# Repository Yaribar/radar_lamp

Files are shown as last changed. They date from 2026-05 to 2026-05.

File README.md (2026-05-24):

# Radar Lamp

ESP32-C3 Super Mini project that dims a lamp based on distance measured by an Acconeer XE121 radar sensor (A121 chip).

## Hardware

- **MCU**: ESP32-C3 Super Mini
- **Sensor**: Acconeer XE121 (A121 radar)

## Wiring

| Signal | ESP32-C3 GPIO |
|---|---|
| ENABLE | 3 |
| INTERRUPT | 5 |
| SCLK | 6 |
| MOSI | 7 |
| MISO | 2 |
| CS | 10 |
| SEL0 | 1 |
| SEL1 | 0 |
| SEL2 | 4 |
| LED | 8 (built-in) |

> **Note:** GPIO 9 (BOOT), 8 (LED), and 18/19 (USB) were intentionally avoided for sensor SEL pins.

## Build

Requires ESP-IDF 6.1.

```bash
# 1. Source IDF (required every new terminal session)
. ~/esp/esp-idf/export.sh

# 2. Go to project
cd ~/esp/radar_lamp

# 3. Set target (only needed once or after cleaning)
idf.py set-target esp32c3

# 4. Build
idf.py build

# 5. Find your port
ls /dev/cu.*

# 6. Flash and open monitor
idf.py -p /dev/cu.YOURPORT flash monitor
```

> To exit the monitor press **Ctrl + ]**

## How it works

### Distance → brightness mapping

| Distance | Brightness |
|---|---|
| ≤ 0.5 m  | 100% |
| 1.15 m | ~50% |
| ≥ 1.8 m  | 0% |

When multiple distances are detected (e.g. paper lamp shade + person), the furthest reading is always used. The sensor start range is set to 0.30 m to exclude the paper shade (~10 cm away).

### Perceptual brightness (gamma correction)

A raw linear PWM sweep from 0→100% does not look linear to the human eye — it appears to jump quickly at low values and barely change at high values. This is because **eyes perceive brightness logarithmically**.

To fix this, a gamma curve (`γ = 2.2`) is applied to the PWM duty cycle:

```
PWM duty = (brightness%)^2.2
```

This makes the lamp appear to change evenly as you move toward or away from it.

### LED state machine

```
valid reading               valid reading
      │                           │
 ┌────▼──────┐  no reading   ┌────▼─────┐
 │ TRACKING  │ ────────────► │ HOLDING  │
 │           │ ◄──────────── │          │
 └───────────┘  reading back └────┬─────┘
                                  │ 3 s timeout
                                  ▼
                            ┌──────────┐
                            │  FADING  │ → slowly → 0%
                            └──────────┘
```

- **TRACKING**: smoothly follows distance (max 2%/50 ms tick ≈ 2.5 s full sweep)
- **HOLDING**: no reading detected, holds current brightness for 3 s
- **FADING**: slowly fades to off (0.5%/tick ≈ 16 s full sweep)

### Key hardware notes

- SPI speed is **10 MHz** — 40 MHz causes calibration failures over breadboard wires
- Sensor range: **0.30 m to 3.0 m** (balanced preset)

## PCB / Hardware design

### Circuit overview

12V barrel jack → Mini 360 step-down → 3.3V for ESP32 + XE121
12V barrel jack → IRLZ44N MOSFET (controlled by GPIO 8 PWM) → 12V LED lamp

### BOM

| Component | Value | Purpose |
|---|---|---|
| ESP32-C3 Super Mini | — | MCU |
| XE121 radar | — | distance sensor |
| IRLZ44N | — | MOSFET, switches 12V lamp via PWM |
| Mini 360 MP2307 | 12V → 3.3V | power regulation |
| Resistor | 100Ω | MOSFET gate series — limits inrush, prevents oscillation |
| Resistor | 10kΩ | MOSFET gate pull-down — keeps lamp off when GPIO floats on boot |
| Capacitor | 100nF ceramic | near ESP32 3.3V pin — absorbs high-freq switching noise |
| Barrel jack | 5.5/2.1mm | 12V input |
| Connector | SH1.0mm 8-pin vertical | XE121 radar |
| Connector | XH2.54 2-pin | 12V lamp output |
| Switch | SPST | power on/off |

### Notes
- No flyback diode needed — lamp is a resistive LED load, no inductive spike
- No fuse on board — power supply has built-in protection
- 100µF on 12V input not needed — Mini 360 + regulated PSU covers it
- IRLZ44N is rated 47A/55V, far above what a 12V LED lamp needs — chosen for logic-level gate compatibility with 3.3V GPIO
- Lamp connector XH2.54 is rated for up to ~3A — verify lamp wattage stays within that (W/12V < 3A, so under 36W)

## License

Acconeer source files are licensed under BSD 3-Clause. See [LICENSES/license_acconeer.txt](LICENSES/license_acconeer.txt).

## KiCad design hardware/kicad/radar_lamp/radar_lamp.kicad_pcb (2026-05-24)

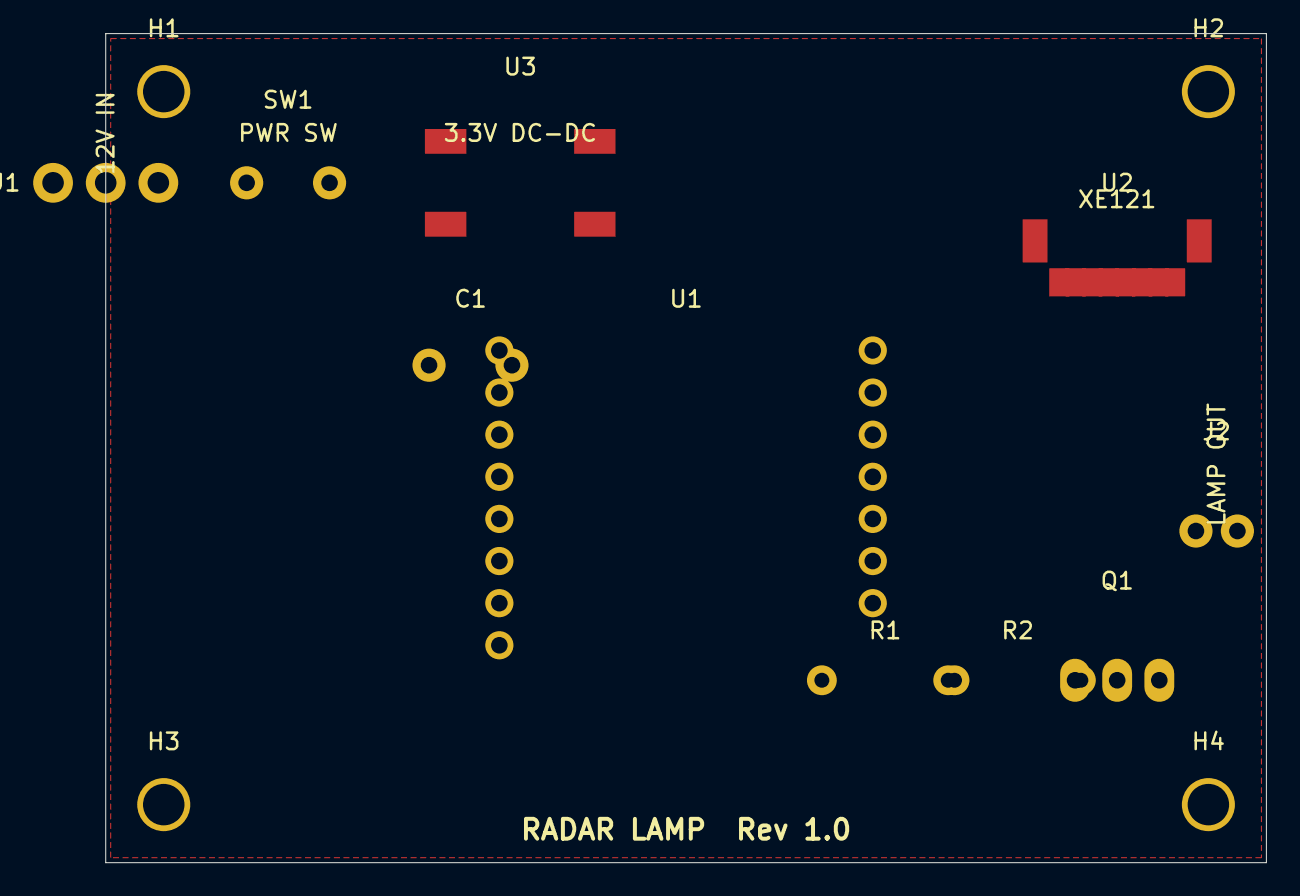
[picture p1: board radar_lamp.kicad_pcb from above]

Board: 2 copper layers, 70.0 x 50.0 mm, 14 parts (0 on the bottom side), 11 nets, no tracks yet.

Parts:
C1: 100nF; C_Disc_D5.0mm_W2.5mm_P5.00mm
H1, H2, H3, H4: MountingHole_2.5mm
J1: Barrel_Jack_5.5/2.1mm; BarrelJack_Horizontal_54-00166
J2: LED_Lamp_12V; JST_XH_B2B-XH-A_1x02_P2.50mm_Vertical
Q1: IRLZ44N; TO-220-3_Vertical
R1: 100R; R_Axial_DIN0207_L6.3mm_D2.5mm_P7.62mm_Horizontal
R2: 10k; R_Axial_DIN0207_L6.3mm_D2.5mm_P7.62mm_Horizontal
SW1: SW_SPST; SW_Slide_1P2T_CK_OS102011MS2QN1
U1: ESP32-C3-SuperMini
U2: Acconeer_XE121; JST_SH_SM08B-SRSS-TB_1x08-1MP_P1mm_Horizontal
U3: Mini360_3V3; Mini360

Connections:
+3V3: C1.1, U1.1, U2.1, U3.3
+12V: J1.1, SW1.1
+12V_SWITCHED: J2.1, SW1.2, U3.1
GND: C1.2, J1.2, Q1.3, R2.2, U1.2, U1.14, U2.2, U3.2, U3.4
LED_PWM: R1.1, U1.7
RADAR_EN: U1.13, U2.7
RADAR_INT: U1.4, U2.8
SPI_CS: U1.8, U2.6
SPI_MISO: U1.12, U2.4
SPI_MOSI: U1.6, U2.3
SPI_SCLK: U1.5, U2.5

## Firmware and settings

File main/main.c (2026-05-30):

// Copyright (c) Acconeer AB, 2022-2025
// All rights reserved
// This file is subject to the terms and conditions defined in the file
// 'LICENSES/license_acconeer.txt', (BSD 3-Clause License) which is part
// of this source code package.

#include <stdbool.h>
#include <stdint.h>
#include <stdio.h>
#include <stdlib.h>

#include "led_dimmer.h"

#include "acc_definitions_a121.h"
#include "acc_detector_distance.h"
#include "acc_hal_definitions_a121.h"
#include "acc_hal_integration_a121.h"
#include "acc_integration.h"
#include "acc_integration_log.h"
#include "acc_rss_a121.h"
#include "acc_sensor.h"
#include "acc_version.h"

/** \example example_detector_distance.c
 * @brief This is an example on how the Detector Distance API can be used
 * @n
 * This example executes as follows:
 *   - Retrieve HAL integration
 *   - Initialize distance detector resources:
 *     + Create distance detector configuration
 *     + Update configuration settings
 *     + Create Distance detector handle
 *     + Create buffer for detector calibration data
 *     + Create buffer for sensor data
 *   - Create and calibrate the sensor
 *   - Calibrate the detector
 *   - Measure distances with the detector (loop):
 *     + Prepare sensor with the detector
 *     + Measure and wait until a read can be done
 *     + Process measurement and print the result
 *     + Handle "calibration_needed" indication
 *   - Cleanup:
 *     + Destroy detector configuration
 *     + Destroy detector handle
 *     + Destroy sensor data buffer
 *     + Destroy detector calibration data buffer
 */

typedef enum
{
	DISTANCE_PRESET_CONFIG_NONE = 0,
	DISTANCE_PRESET_CONFIG_BALANCED,
	DISTANCE_PRESET_CONFIG_HIGH_ACCURACY,
} distance_preset_config_t;

#define SENSOR_ID (1U)
// 2 seconds should be enough even for long ranges and high signal quality
#define SENSOR_TIMEOUT_MS (2000U)

typedef struct
{
	acc_sensor_t                     *sensor;
	acc_detector_distance_config_t   *config;
	acc_detector_distance_handle_t   *handle;
	void                             *buffer;
	uint32_t                          buffer_size;
	uint8_t                          *detector_cal_result_static;
	uint32_t                          detector_cal_result_static_size;
	acc_detector_cal_result_dynamic_t detector_cal_result_dynamic;
} distance_detector_resources_t;

static void cleanup(distance_detector_resources_t *resources);

static void set_config(acc_detector_distance_config_t *detector_config, distance_preset_config_t preset);

static bool initialize_detector_resources(distance_detector_resources_t *resources);

static bool do_sensor_calibration(acc_sensor_t *sensor, acc_cal_result_t *sensor_cal_result, void *buffer, uint32_t buffer_size);

static bool do_full_detector_calibration(distance_detector_resources_t *resources, const acc_cal_result_t *sensor_cal_result);

static bool do_detector_calibration_update(distance_detector_resources_t *resources, const acc_cal_result_t *sensor_cal_result);

static bool do_detector_get_next(distance_detector_resources_t  *resources,
                                 const acc_cal_result_t         *sensor_cal_result,
                                 acc_detector_distance_result_t *result);

static void print_distance_result(const acc_detector_distance_result_t *result);

int app_main(int argc, char *argv[]);

int app_main(int argc, char *argv[])
{
	(void)argc;
	(void)argv;
	distance_detector_resources_t resources = {0};

	led_dimmer_init();

	printf("Acconeer software version %s\n", acc_version_get());

	const acc_hal_a121_t *hal = acc_hal_rss_integration_get_implementation();

	if (!acc_rss_hal_register(hal))
	{
		return EXIT_FAILURE;
	}

	resources.config = acc_detector_distance_config_create();
	if (resources.config == NULL)
	{
		printf("acc_detector_distance_config_create() failed\n");
		cleanup(&resources);
		return EXIT_FAILURE;
	}

	set_config(resources.config, DISTANCE_PRESET_CONFIG_BALANCED);

	if (!initialize_detector_resources(&resources))
	{
		printf("Initializing detector resources failed\n");
		cleanup(&resources);
		return EXIT_FAILURE;
	}

	// Print the configuration
	acc_detector_distance_config_log(resources.handle, resources.config);

	/* Turn the sensor on */
	acc_hal_integration_sensor_supply_on(SENSOR_ID);
	acc_hal_integration_sensor_enable(SENSOR_ID);

	resources.sensor = acc_sensor_create(SENSOR_ID);
	if (resources.sensor == NULL)
	{
		printf("acc_sensor_create() failed\n");
		cleanup(&resources);
		return EXIT_FAILURE;
	}

	acc_cal_result_t sensor_cal_result;

	if (!do_sensor_calibration(resources.sensor, &sensor_cal_result, resources.buffer, resources.buffer_size))
	{
		printf("Sensor calibration failed\n");
		cleanup(&resources);
		return EXIT_FAILURE;
	}

	if (!do_full_detector_calibration(&resources, &sensor_cal_result))
	{
		printf("Detector calibration failed\n");
		cleanup(&resources);
		return EXIT_FAILURE;
	}

	while (true)
	{
		acc_detector_distance_result_t result = {0};

		if (!do_detector_get_next(&resources, &sensor_cal_result, &result))
		{
			printf("Could not get next result\n");
			cleanup(&resources);
			return EXIT_FAILURE;
		}

		/* If "calibration needed" is indicated, the sensor needs to be recalibrated and the detector calibration updated */
		if (result.calibration_needed)
		{
			led_dimmer_update(0.0f, false);
			printf("Sensor recalibration and detector calibration update needed ... \n");

			if (!do_sensor_calibration(resources.sensor, &sensor_cal_result, resources.buffer, resources.buffer_size))
			{
				printf("Sensor calibration failed\n");
				cleanup(&resources);
				return EXIT_FAILURE;
			}

			/* Once the sensor is recalibrated, the detector calibration should be updated and measuring can continue. */
			if (!do_detector_calibration_update(&resources, &sensor_cal_result))
			{
				printf("Detector calibration update failed\n");
				cleanup(&resources);
				return EXIT_FAILURE;
			}

			printf("Sensor recalibration and detector calibration update done!\n");
		}
		else if (result.num_distances == 0)
		{
			led_dimmer_update(0.0f, false);
		}
		else
		{
			// Multiple readings possible (e.g. paper lamp + person).
			// Always use the furthest distance — paper is always closest.
			float max_dist = 0.0f;
			for (uint8_t i = 0; i < result.num_distances; i++)
			{
				if (result.distances[i] > max_dist)
					max_dist = result.distances[i];
			}
			print_distance_result(&result);
			// If the furthest peak is beyond the dim threshold it's a static
			// reflector (wall, furniture) — treat as no presence so the lamp
			// fades out instead of staying on indefinitely.
			if (max_dist >= DIST_FULL_DIM_M)
				led_dimmer_update(0.0f, false);
			else
				led_dimmer_update(max_dist, true);
		}
	}

	cleanup(&resources);

	printf("Done!\n");

	return EXIT_SUCCESS;
}

static void cleanup(distance_detector_resources_t *resources)
{
	acc_hal_integration_sensor_disable(SENSOR_ID);
	acc_hal_integration_sensor_supply_off(SENSOR_ID);

	acc_detector_distance_config_destroy(resources->config);
	acc_detector_distance_destroy(resources->handle);

	acc_integration_mem_free(resources->buffer);
	acc_integration_mem_free(resources->detector_cal_result_static);

	if (resources->sensor != NULL)
	{
		acc_sensor_destroy(resources->sensor);
	}
}

static void set_config(acc_detector_distance_config_t *detector_config, distance_preset_config_t preset)
{
	// Add configuration of the detector here
	switch (preset)
	{
		case DISTANCE_PRESET_CONFIG_NONE:
			// Add configuration of the detector here
			break;

		case DISTANCE_PRESET_CONFIG_BALANCED:
			acc_detector_distance_config_start_set(detector_config, 0.30f);
			acc_detector_distance_config_end_set(detector_config, 3.0f);
			acc_detector_distance_config_max_step_length_set(detector_config, 0U);
			acc_detector_distance_config_max_profile_set(detector_config, ACC_CONFIG_PROFILE_5);
			acc_detector_distance_config_reflector_shape_set(detector_config, ACC_DETECTOR_DISTANCE_REFLECTOR_SHAPE_GENERIC);
			acc_detector_distance_config_peak_sorting_set(detector_config, ACC_DETECTOR_DISTANCE_PEAK_SORTING_STRONGEST);
			acc_detector_distance_config_threshold_method_set(detector_config, ACC_DETECTOR_DISTANCE_THRESHOLD_METHOD_CFAR);
			acc_detector_distance_config_threshold_sensitivity_set(detector_config, 0.5f);
			acc_detector_distance_config_signal_quality_set(detector_config, 15.0f);
			acc_detector_distance_config_close_range_leakage_cancellation_set(detector_config, false);
			break;

		case DISTANCE_PRESET_CONFIG_HIGH_ACCURACY:
			acc_detector_distance_config_start_set(detector_config, 0.25f);
			acc_detector_distance_config_end_set(detector_config, 3.0f);
			acc_detector_distance_config_max_step_length_set(detector_config, 2U);
			acc_detector_distance_config_max_profile_set(detector_config, ACC_CONFIG_PROFILE_3);
			acc_detector_distance_config_reflector_shape_set(detector_config, ACC_DETECTOR_DISTANCE_REFLECTOR_SHAPE_GENERIC);
			acc_detector_distance_config_peak_sorting_set(detector_config, ACC_DETECTOR_DISTANCE_PEAK_SORTING_STRONGEST);
			acc_detector_distance_config_threshold_method_set(detector_config, ACC_DETECTOR_DISTANCE_THRESHOLD_METHOD_CFAR);
			acc_detector_distance_config_threshold_sensitivity_set(detector_config, 0.5f);
			acc_detector_distance_config_signal_quality_set(detector_config, 20.0f);
			acc_detector_distance_config_close_range_leakage_cancellation_set(detector_config, false);
			break;
	}
}

static bool initialize_detector_resources(distance_detector_resources_t *resources)
{
	resources->handle = acc_detector_distance_create(resources->config);
	if (resources->handle == NULL)
	{
		printf("acc_detector_distance_create() failed\n");
		return false;
	}

	if (!acc_detector_distance_get_sizes(resources->handle, &(resources->buffer_size), &(resources->detector_cal_result_static_size)))
	{
		printf("acc_detector_distance_get_sizes() failed\n");
		return false;
	}

	resources->buffer = acc_integration_mem_alloc(resources->buffer_size);
	if (resources->buffer == NULL)
	{
		printf("sensor buffer allocation failed\n");
		return false;
	}

	resources->detector_cal_result_static = acc_integration_mem_alloc(resources->detector_cal_result_static_size);
	if (resources->detector_cal_result_static == NULL)
	{
		printf("calibration buffer allocation failed\n");
		return false;
	}

	return true;
}

static bool do_sensor_calibration(acc_sensor_t *sensor, acc_cal_result_t *sensor_cal_result, void *buffer, uint32_t buffer_size)
{
	bool           status              = false;
	bool           cal_complete        = false;
	const uint16_t calibration_retries = 1U;

	// Random disturbances may cause the calibration to fail. At failure, retry at least once.
	for (uint16_t i = 0; !status && (i <= calibration_retries); i++)
	{
		// Reset sensor before calibration by disabling/enabling it
		acc_hal_integration_sensor_disable(SENSOR_ID);
		acc_hal_integration_sensor_enable(SENSOR_ID);

		do
		{
			status = acc_sensor_calibrate(sensor, &cal_complete, sensor_cal_result, buffer, buffer_size);

			if (status && !cal_complete)
			{
				status = acc_hal_integration_wait_for_sensor_interrupt(SENSOR_ID, SENSOR_TIMEOUT_MS);
			}
		} while (status && !cal_complete);
	}

	if (status)
	{
		/* Reset sensor after calibration by disabling/enabling it */
		acc_hal_integration_sensor_disable(SENSOR_ID);
		acc_hal_integration_sensor_enable(SENSOR_ID);
	}

	return status;
}

static bool do_full_detector_calibration(distance_detector_resources_t *resources, const acc_cal_result_t *sensor_cal_result)
{
	bool done = false;
	bool status;

	do
	{
		status = acc_detector_distance_calibrate(resources->sensor,
		                                         resources->handle,
		                                         sensor_cal_result,
		                                         resources->buffer,
		                                         resources->buffer_size,
		                                         resources->detector_cal_result_static,
		                                         resources->detector_cal_result_static_size,
		                                         &resources->detector_cal_result_dynamic,
		                                         &done);

		if (status && !done)
		{
			status = acc_hal_integration_wait_for_sensor_interrupt(SENSOR_ID, SENSOR_TIMEOUT_MS);
		}
	} while (status && !done);

	return status;
}

static bool do_detector_calibration_update(distance_detector_resources_t *resources, const acc_cal_result_t *sensor_cal_result)
{
	bool done = false;
	bool status;

	do
	{
		status = acc_detector_distance_update_calibration(resources->sensor,
		                                                  resources->handle,
		                                                  sensor_cal_result,
		                                                  resources->buffer,
		                                                  resources->buffer_size,
		                                                  &resources->detector_cal_result_dynamic,
		                                                  &done);

		if (status && !done)
		{
			status = acc_hal_integration_wait_for_sensor_interrupt(SENSOR_ID, SENSOR_TIMEOUT_MS);
		}
	} while (status && !done);

	return status;
}

static bool do_detector_get_next(distance_detector_resources_t  *resources,
                                 const acc_cal_result_t         *sensor_cal_result,
                                 acc_detector_distance_result_t *result)
{
	bool result_available = false;

	do
	{
		if (!acc_detector_distance_prepare(resources->handle,
		                                   resources->config,
		                                   resources->sensor,
		                                   sensor_cal_result,
		                                   resources->buffer,
		                                   resources->buffer_size))
		{
			printf("acc_detector_distance_prepare() failed\n");
			return false;
		}

		if (!acc_sensor_measure(resources->sensor))
		{
			printf("acc_sensor_measure() failed\n");
			return false;
		}

		if (!acc_hal_integration_wait_for_sensor_interrupt(SENSOR_ID, SENSOR_TIMEOUT_MS))
		{
			printf("Sensor interrupt timeout\n");
			return false;
		}

		if (!acc_sensor_read(resources->sensor, resources->buffer, resources->buffer_size))
		{
			printf("acc_sensor_read() failed\n");
			return false;
		}

		if (!acc_detector_distance_process(resources->handle,
		                                   resources->buffer,
		                                   resources->detector_cal_result_static,
		                                   &resources->detector_cal_result_dynamic,
		                                   &result_available,
		                                   result))
		{
			printf("acc_detector_distance_process() failed\n");
			return false;
		}
	} while (!result_available);

	return true;
}

static void print_distance_result(const acc_detector_distance_result_t *result)
{
	printf("%d detected distances", result->num_distances);
	if (result->num_distances > 0)
	{
		printf(": ");

		for (uint8_t i = 0; i < result->num_distances; i++)
		{
			printf("%" PRIfloat " m ", ACC_LOG_FLOAT_TO_INTEGER(result->distances[i]));
		}
	}

	printf("\n");
}

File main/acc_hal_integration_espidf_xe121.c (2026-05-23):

// Copyright (c) Acconeer AB, 2022-2025
// All rights reserved
// This file is subject to the terms and conditions defined in the file
// 'LICENSES/license_acconeer.txt', (BSD 3-Clause License) which is part
// of this source code package.

#include <stdbool.h>
#include <stdint.h>
#include <string.h>

#include "acc_definitions_common.h"
#include "acc_hal_definitions_a121.h"
#include "acc_hal_integration_a121.h"
#include "acc_integration.h"
#include "acc_integration_log.h"

#include "driver/gpio.h"
#include "driver/spi_master.h"
#include "esp_sleep.h"

#include "freertos/FreeRTOS.h"
#include "freertos/semphr.h"

/**
 * @brief The number of sensors available on the board
 */
#define SENSOR_COUNT 1

#define GPIO_SEL0 1
#define GPIO_SEL1 0
#define GPIO_SEL2 4

#define GPIO_ENABLE    3
#define GPIO_INTERRUPT 5
#define GPIO_SCLK      6
#define GPIO_MOSI      7
#define GPIO_MISO      2
#define GPIO_CS        10

static spi_device_handle_t spi = NULL;

static StaticSemaphore_t xSemaphoreBuffer;
static SemaphoreHandle_t isr_sem = NULL;

/**
 * @brief Size of SPI transfer buffer
 */
#define SPI_MAX_TRANSFER_SIZE 8192

/**
 * @brief Transfer speed in Hz
 */
#define SPI_TRANSFER_SPEED SPI_MASTER_FREQ_10M

//----------------------------------------
// Implementation of RSS HAL handlers
//----------------------------------------

static void acc_hal_integration_sensor_transfer(acc_sensor_id_t sensor_id, uint8_t *buffer, size_t buffer_size)
{
	esp_err_t         ret;
	spi_transaction_t t;

	memset(&t, 0, sizeof(t));
	t.length    = buffer_size * 8;
	t.tx_buffer = buffer;
	t.rx_buffer = buffer;
	t.user      = (void *)1;
	ret         = spi_device_polling_transmit(spi, &t);
	ESP_ERROR_CHECK(ret);
}

static void isr_handler(void *args)
{
	BaseType_t xHigherPriorityTaskWoken = pdFALSE;

	xSemaphoreGiveFromISR(isr_sem, &xHigherPriorityTaskWoken);
	portYIELD_FROM_ISR(xHigherPriorityTaskWoken);
}

bool acc_hal_integration_wait_for_sensor_interrupt(acc_sensor_id_t sensor_id, uint32_t timeout_ms)

{
	(void)sensor_id; // Ignore parameter sensor_id

	int interupt_level = gpio_get_level(GPIO_INTERRUPT);

	if (interupt_level == 1)
	{
		xSemaphoreTake(isr_sem, 0);
		return true;
	}
	else
	{
		return xSemaphoreTake(isr_sem, timeout_ms / portTICK_PERIOD_MS) == pdTRUE;
	}
}

static const acc_hal_a121_t hal = {
    .max_spi_transfer_size = SPI_MAX_TRANSFER_SIZE,

    .mem_alloc = malloc,
    .mem_free  = free,

    .transfer = acc_hal_integration_sensor_transfer,
    .log      = acc_integration_log,

    .optimization.transfer16 = NULL,
};

const acc_hal_a121_t *acc_hal_rss_integration_get_implementation(void)
{
	gpio_set_direction(GPIO_SEL0, GPIO_MODE_OUTPUT);
	gpio_set_direction(GPIO_SEL1, GPIO_MODE_OUTPUT);
	gpio_set_direction(GPIO_SEL2, GPIO_MODE_OUTPUT);
	gpio_set_level(GPIO_SEL0, 0);
	gpio_set_level(GPIO_SEL1, 0);
	gpio_set_level(GPIO_SEL2, 0);
	gpio_set_direction(GPIO_ENABLE, GPIO_MODE_OUTPUT);

	isr_sem = xSemaphoreCreateBinaryStatic(&xSemaphoreBuffer);
	configASSERT(isr_sem);

	esp_rom_gpio_pad_select_gpio(GPIO_INTERRUPT);
	gpio_set_direction(GPIO_INTERRUPT, GPIO_MODE_INPUT);
	gpio_pulldown_en(GPIO_INTERRUPT);
	gpio_pullup_dis(GPIO_INTERRUPT);
	gpio_set_intr_type(GPIO_INTERRUPT, GPIO_INTR_POSEDGE);

	gpio_install_isr_service(0);
	gpio_isr_handler_add(GPIO_INTERRUPT, isr_handler, NULL);

	esp_err_t        ret;
	spi_bus_config_t buscfg = {.miso_io_num     = GPIO_MISO,
	                           .mosi_io_num     = GPIO_MOSI,
	                           .sclk_io_num     = GPIO_SCLK,
	                           .quadwp_io_num   = -1,
	                           .quadhd_io_num   = -1,
	                           .max_transfer_sz = SPI_MAX_TRANSFER_SIZE};

	spi_device_interface_config_t devcfg = {
	    .clock_speed_hz = SPI_TRANSFER_SPEED,
	    .mode           = 0,
	    .spics_io_num   = GPIO_CS,
	    .queue_size     = 7,
	    .pre_cb         = NULL,
	};

	ret = spi_bus_initialize(SPI2_HOST, &buscfg, SPI_DMA_CH_AUTO);
	ESP_ERROR_CHECK(ret);
	printf("[HAL] SPI bus initialized (MISO=%d MOSI=%d SCLK=%d CS=%d)\n",
	       GPIO_MISO, GPIO_MOSI, GPIO_SCLK, GPIO_CS);

	ret = spi_bus_add_device(SPI2_HOST, &devcfg, &spi);
	ESP_ERROR_CHECK(ret);
	printf("[HAL] SPI device added at %d Hz\n", SPI_TRANSFER_SPEED);

	return &hal;
}

void acc_hal_integration_sensor_supply_on(acc_sensor_id_t sensor_id)
{
	// There is no power supply control on the XE121
	(void)sensor_id;
}

void acc_hal_integration_sensor_supply_off(acc_sensor_id_t sensor_id)
{
	// There is no power supply control on the XE121
	(void)sensor_id;
}

void acc_hal_integration_sensor_enable(acc_sensor_id_t sensor_id)
{
	(void)sensor_id; // Ignore parameter sensor_id

	gpio_set_level(GPIO_ENABLE, 1);

	// Wait 2 ms to make sure that the sensor crystal have time to stabilize
	acc_integration_sleep_us(2000);

	// Reset the interrupt semaphore
	xSemaphoreTake(isr_sem, 0);
}

void acc_hal_integration_sensor_disable(acc_sensor_id_t sensor_id)
{
	(void)sensor_id; // Ignore parameter sensor_id

	gpio_set_level(GPIO_ENABLE, 0);
	acc_integration_sleep_us(2000);
}

uint16_t acc_hal_integration_sensor_count(void)
{
	return SENSOR_COUNT;
}

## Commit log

2026-05-23 Initial commit: radar_lamp self-contained project
    Based on Acconeer XE121 example_detector_distance.
    All sources, headers and prebuilt libs copied into one folder.
    BSD 3-Clause license from Acconeer included.
    Hardware: ESP32-C3 Super Mini + XE121 radar sensor
    Working config: SPI at 10MHz (40MHz causes calibration failures
    on breadboard wires)
    Pin mapping:
    ENABLE=GPIO3, INTERRUPT=GPIO5, SCLK=GPIO6
    MOSI=GPIO7, MISO=GPIO2, CS=GPIO10
    SEL0=GPIO1, SEL1=GPIO0, SEL2=GPIO4
    LED=GPIO8 (built-in, blinks on each measurement)
2026-05-23 feat: LED dimmer with state machine and smooth transitions
    - New led_dimmer.c/.h module with FreeRTOS task
    - LEDC PWM on GPIO8 (built-in LED), 5kHz, 10-bit resolution
    - Distance → brightness: 0.5m=100%, 2.5m=0% (linear)
    - Smooth tracking: max 2%/tick (50ms) → ~2.5s full sweep
    - State machine: TRACKING → HOLDING (3s) → FADING (0.5%/tick)
    - Multiple readings: always picks furthest (ignores paper lamp)
    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
2026-05-23 feat: gamma correction for perceptual brightness + update docs
    Human eyes perceive brightness logarithmically. Linear PWM
    looks like a sudden jump at low values. Applying gamma=2.2
    makes the transition appear even across the distance range.
    README updated with: brightness mapping table, gamma explanation,
    state machine diagram, hardware notes.
    [led_dimmer.c]
2026-05-24 docs: add PCB BOM and circuit design notes
2026-05-24 feat: add KiCad 10 PCB project for radar lamp controller
    Full schematic and PCB layout in hardware/kicad/radar_lamp/:
    - ESP32-C3 Super Mini + Acconeer XE121 + IRLZ44N + Mini360 DC-DC
    - 70×50mm 2-layer board, GND pour on F.Cu and B.Cu
    - JST SH 8-pin connector for XE121, XH2.54 for LED output
    - Verified loads cleanly in KiCad 10.0.3 (kicad-cli exit 0)
    [radar_lamp.kicad_pcb, radar_lamp.kicad_sch]
2026-05-30 fix: treat far-only detections as no presence so lamp turns off
    When the furthest detected peak is >= DIST_FULL_DIM_M (1.8 m) it is
    likely a static reflector (wall, furniture) rather than a person.
    Calling led_dimmer_update with valid=false in that case lets the
    hold/fade state machine run, so the lamp actually turns off instead
    of staying on indefinitely.
    DIST_FULL_DIM_M is moved to led_dimmer.h so main.c can share it.
    [led_dimmer.c, main.c]
2026-05-31 feat: smooth LED dimming with adaptive filtering and two-stage fade
    - Treat far-only detections (>= DIST_FULL_DIM_M) as no presence so lamp
    fades out instead of staying on when only walls/furniture are detected
    - 10ms LED task tick for smoother brightness transitions
    - Distance smoothing pipeline: 3-sample median filter to reject spikes,
    followed by adaptive EMA (alpha scales with movement speed) so slow
    steps are smoothed while fast movement is followed immediately
    - Debounce invalid readings (6 consecutive required) to prevent flicker
    during slow steps
    - 5s hold timeout before fading starts, giving extra buffer for slow walkers
    - Exponential fade (0.96x/tick) with two-stage tail: s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
    [led_dimmer.c]
